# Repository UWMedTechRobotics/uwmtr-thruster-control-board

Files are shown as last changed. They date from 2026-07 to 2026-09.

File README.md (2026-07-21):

# Thruster Control Board - Revision 2

## Progress Notes
- Designed circuit board revision 1 using Altium Designer.
- Wrote firmware for testing circuitry on revision 1.
    - Wasn't able to use revision 1 tests due to faults in circuit design.
- Designed circuit board revision 2 using Altium Designer.

## Todo Things & Priority
### High
- [x] [@AdrianTarantino](https://github.com/AdrianTarantino) | Solder crystal 
oscillator to board.

- [ ] Test device functionality. View [this repository](https://github.com/UWMedTechRobotics/ESC_V1_Firmware_Tests/tree/main).
    - [ ] Validate I2C, GPIO, PWM and ADC.

- [ ] Implement firmware for interfacing with onboard electronics:
    - [ ] [IMU (BNO055)](https://www.bosch-sensortec.com/media/boschsensortec/downloads/datasheets/bst-bno055-ds000.pdf).
    Note that this may be controlled by Orange Pi instead.
    - [ ] Leak Sensor (ask Daniel).
    - [ ] Solonoids (ask Daniel).
    - [ ] Serial communication via USB Type-C.
        - Speak with Abdur about what information needs to be communicated and
        how that information needs to be formatted.
        - Use PuTTY to validate that it's working.
    - [ ] [@AdrianTarantino](https://github.com/AdrianTarantino) | 3-Phase BLDC 
    motors.
    - [x] [@AdrianTarantino](https://github.com/AdrianTarantino) | Muxes
    - [x] [@AdrianTarantino](https://github.com/AdrianTarantino) | [LED Driver](https://use.365.altium.com/librarycomponentsapi/api/v1/References/6CBF2630-7D49-4BC0-9B47-311861A12B9A). LED colour should follow this
    priority:
        - Red when failure.
        - Green when motors spinning.
        - Purple when communicating with external device.
        - Blue when idle.

### Medium
- [ ] Conan | Design mounting bracket for board.

- [ ] Source stantions for stacking power board, sonar board and thruster board.

### Low
- [ ] Develop diagnostic app:
    - Desktop app on PC
    - Sends commands via USB to the board.

- [ ] Add release to [GitHub repository](https://github.com/UWMedTechRobotics/uwmtr-thruster-control-board).
    - STEP file.
    - NC Drill, Gerber
    - BOM, Pick & Place

- [ ] Document everything that needs to be changed for revision 3:
    - [ ] Add 3-phase BLDC driver chip.
        - Ideally be able to set speed & direction via I2C or SPI.
    - [ ] Add BNO055 IMU to the board instead of the current IMU on the board.
    - [ ] Replace the debug connector with pin headers.
    - [ ] Add USB to UART chip to simplify USB communications.
    - [ ] Add an additional onboard LED purely for signalling that power is on.
     
# Revision 3 Notes
## Electrical
- Update motor control circuitry to use [the TI MCF8316A](https://www.ti.com/product/MCF8316A#pps).
    - Significantly simplifies electrical system and number of components on the board.
    - Available on JLCPCB parts library.
- Simplify USB communication with [TI TUSB3410](https://www.ti.com/product/TUSB3410).
    - Converts USB data to UART.
 - Add [BNO055](https://www.digikey.ca/short/m2jcv0r0) for IMU related data.
    - Available on JLCPCB parts library.
- Add dedicated LED purely for indicating power-on.
- Use Power MOSFETs

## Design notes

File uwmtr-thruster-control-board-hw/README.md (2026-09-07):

# Notes
- Voltage for buck converter must be set with `BUCK_SEL` parameters
    
    | `BUCK_SEL` Value | Voltage |
    | ---------------- | ------- |
    | 0b00 | 3.1 < 3.3 < 3.5 |
    | 0b01 | 4.6 < 5.0 < 5.4 |
    | 0b10 | 3.7 < 4.0 < 4.3 |
    | 0b11 | 5.2 < 5.7 < 6.2 | 

- Source THT 22R 1W resistor for buck converter with.

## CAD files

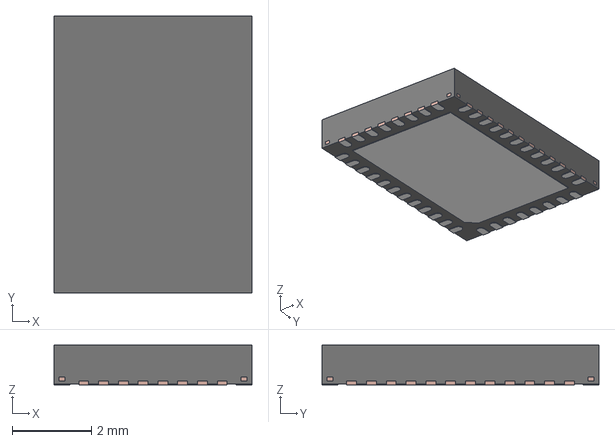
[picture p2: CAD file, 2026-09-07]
uwmtr-thruster-control-board-hw/uwmtr-thruster-control-board-hw-3d-models/TI_MCF8316A1VRGFR.stp
5.00 x 7.00 x 1.00 mm
FRAME

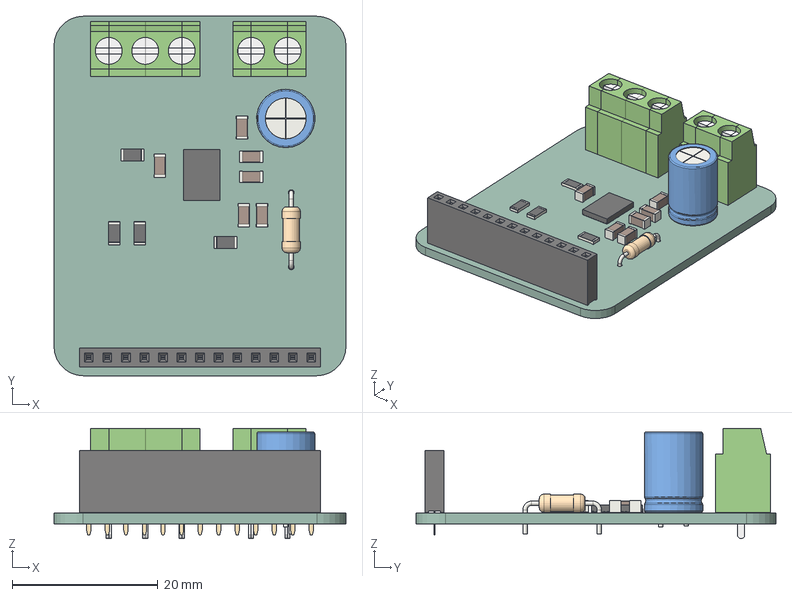
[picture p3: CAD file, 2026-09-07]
uwmtr-thruster-control-board-hw/uwmtr-thruster-control-board-hw-assembly/3d-models/uwmtr-thruster-control-board-hw.step
40.0 x 49.2 x 15.1 mm
R_1206_3216Metric x 4
C_1206_3216Metric x 6
MRT12P5_SX x 2
MRT12P5_CNT x 3
MRT12P5_DX x 2
C_Radial_D80mm_H115mm_P350mm
PinSocket_1x13_P2.54mm_Vertical
R_Axial_DIN0207_L63mm_D25mm_P1016mm_Horizontal
uwmA60_PCB

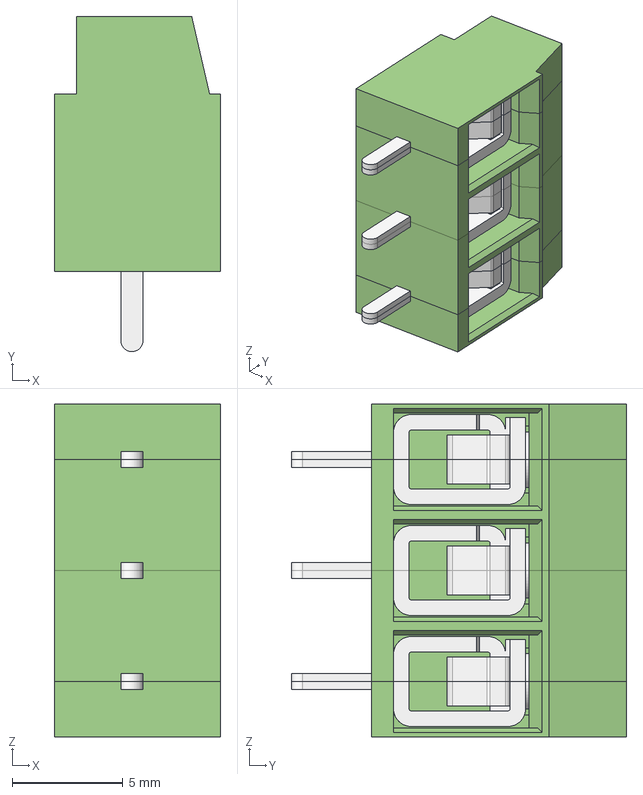
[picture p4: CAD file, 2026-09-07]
uwmtr-thruster-control-board-hw/uwmtr-thruster-control-board-hw-3d-models/Download_STP_691137710003_rev1.stp
7.50 x 15.1 x 15.0 mm
MRT12P5_SX
MRT12P5_CNT x 2
MRT12P5_DX

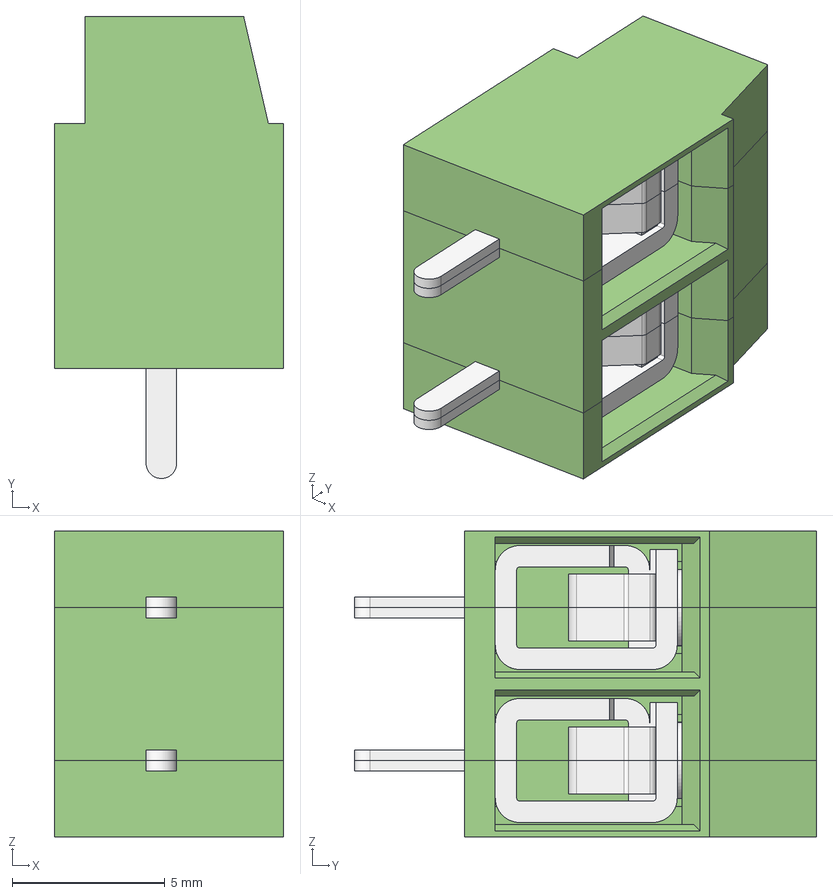
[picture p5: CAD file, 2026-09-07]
uwmtr-thruster-control-board-hw/uwmtr-thruster-control-board-hw-3d-models/691137710002.step
7.50 x 15.1 x 10.0 mm
MRT12P5_SX
MRT12P5_CNT
MRT12P5_DX

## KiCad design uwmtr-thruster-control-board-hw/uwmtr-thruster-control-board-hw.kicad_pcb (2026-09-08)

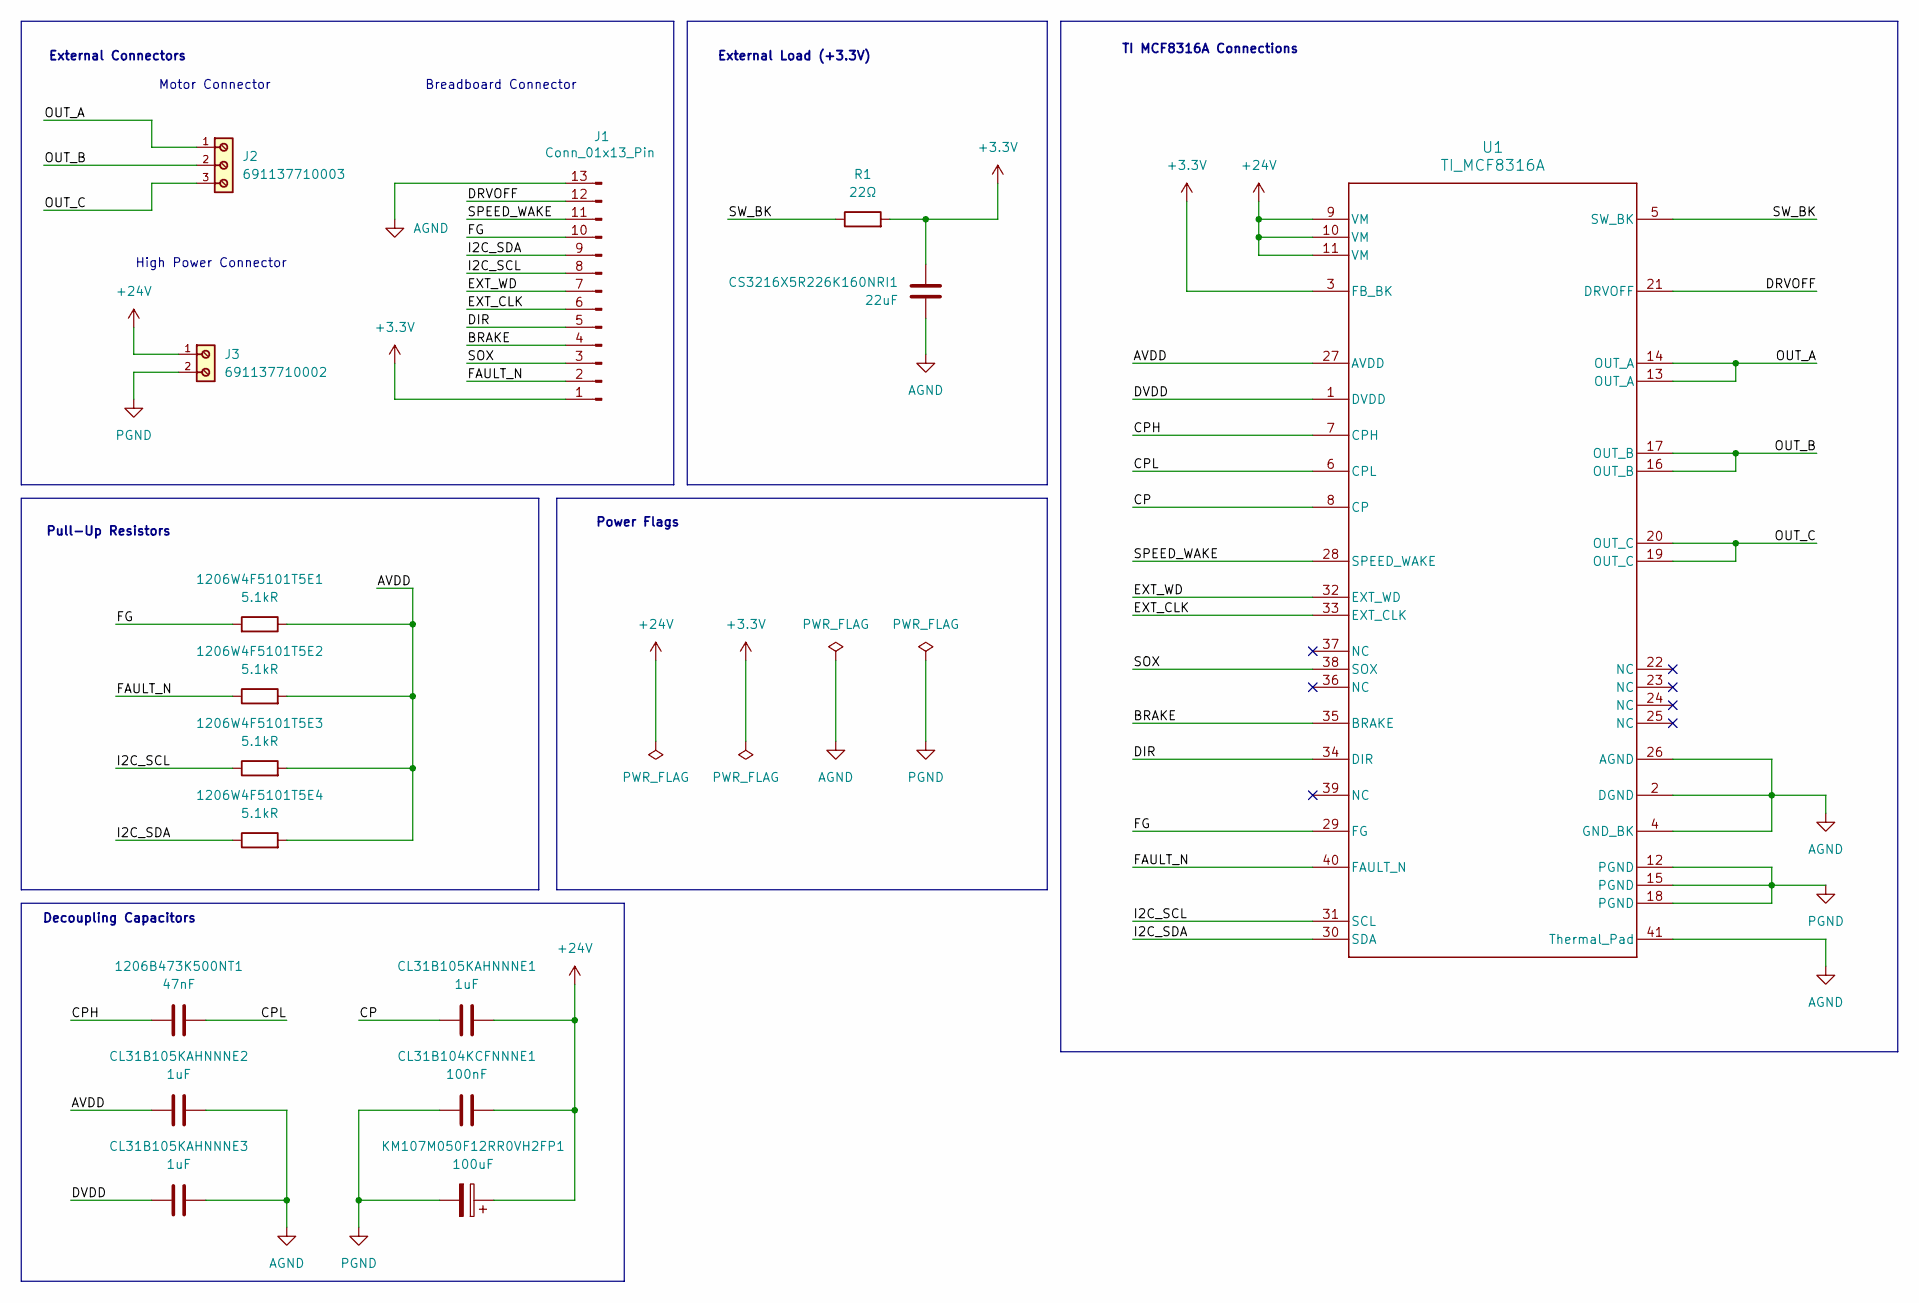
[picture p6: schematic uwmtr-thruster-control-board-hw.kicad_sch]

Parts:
1206B473K500NT1: 47nF; C_1206_3216Metric; JLCPCB Part # C1870
1206W4F5101T5E1, 1206W4F5101T5E2, 1206W4F5101T5E3, 1206W4F5101T5E4: 5.1kR; R_1206_3216Metric; JLCPCB Part # C26033
CL31B104KCFNNNE1: 100nF; C_1206_3216Metric; JLCPCB Part # C1945
CL31B105KAHNNNE1, CL31B105KAHNNNE2, CL31B105KAHNNNE3: 1uF; C_1206_3216Metric; JLCPCB Part # C28322
CS3216X5R226K160NRI1: 22uF; C_1206_3216Metric; JLCPCB Part # C513771
J1: Conn_01x13_Pin; PinSocket_1x13_P2.54mm_Vertical
J2: 691137710003
J3: 691137710002
KM107M050F12RR0VH2FP1: 100uF; C_Radial_D8.0mm_H11.5mm_P3.50mm; JLCPCB Part # C2749
R1: 22Ω; R_Axial_DIN0207_L6.3mm_D2.5mm_P10.16mm_Horizontal
U1: TI_MCF8316A; JLCPCB Part # C3681167

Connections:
+3.3V: CS3216X5R226K160NRI1.1, J1.1 (Pin_13), R1.2, U1.3 (FB_BK)
+24V: CL31B104KCFNNNE1.2, CL31B105KAHNNNE1.1, J3.1, KM107M050F12RR0VH2FP1.1, U1.9 (VM), U1.10 (VM), U1.11 (VM)
/AVDD: 1206W4F5101T5E1.1, 1206W4F5101T5E2.2, 1206W4F5101T5E3.2, 1206W4F5101T5E4.2, CL31B105KAHNNNE2.2, U1.27 (AVDD)
/BRAKE: J1.4 (Pin_10), U1.35 (BRAKE)
/CP: CL31B105KAHNNNE1.2, U1.8 (CP)
/CPH: 1206B473K500NT1.1, U1.7 (CPH)
/CPL: 1206B473K500NT1.2, U1.6 (CPL)
/DIR: J1.5 (Pin_9), U1.34 (DIR)
/DRVOFF: J1.12 (Pin_2), U1.21 (DRVOFF)
/DVDD: CL31B105KAHNNNE3.2, U1.1 (DVDD)
/EXT_CLK: J1.6 (Pin_8), U1.33 (EXT_CLK)
/EXT_WD: J1.7, U1.32 (EXT_WD)
/FAULT_N: 1206W4F5101T5E2.1, J1.2 (Pin_12), U1.40 (FAULT_N)
/FG: 1206W4F5101T5E1.2, J1.10 (Pin_4), U1.29 (FG)
/I2C_SCL: 1206W4F5101T5E3.1, J1.8 (Pin_6), U1.31 (SCL)
/I2C_SDA: 1206W4F5101T5E4.1, J1.9 (Pin_5), U1.30 (SDA)
/OUT_A: J2.1, U1.13 (OUT_A), U1.14 (OUT_A)
/OUT_B: J2.2, U1.16 (OUT_B), U1.17 (OUT_B)
/OUT_C: J2.3, U1.19 (OUT_C), U1.20 (OUT_C)
/SOX: J1.3 (Pin_11), U1.38 (SOX)
/SPEED_WAKE: J1.11 (Pin_3), U1.28 (SPEED_WAKE)
/SW_BK: R1.1, U1.5 (SW_BK)
AGND: CL31B105KAHNNNE2.1, CL31B105KAHNNNE3.1, CS3216X5R226K160NRI1.2, J1.13 (Pin_1), U1.2 (DGND), U1.4 (GND_BK), U1.26 (AGND), U1.41 (Thermal_Pad)
PGND: CL31B104KCFNNNE1.1, J3.2, KM107M050F12RR0VH2FP1.2, U1.12 (PGND), U1.15 (PGND), U1.18 (PGND)

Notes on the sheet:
High Power Connector
Decoupling Capacitors
External Connectors
Power Flags
Pull-Up Resistors
TI MCF8316A Connections
Motor Connector
Breadboard Connector
External Load (+3.3V)

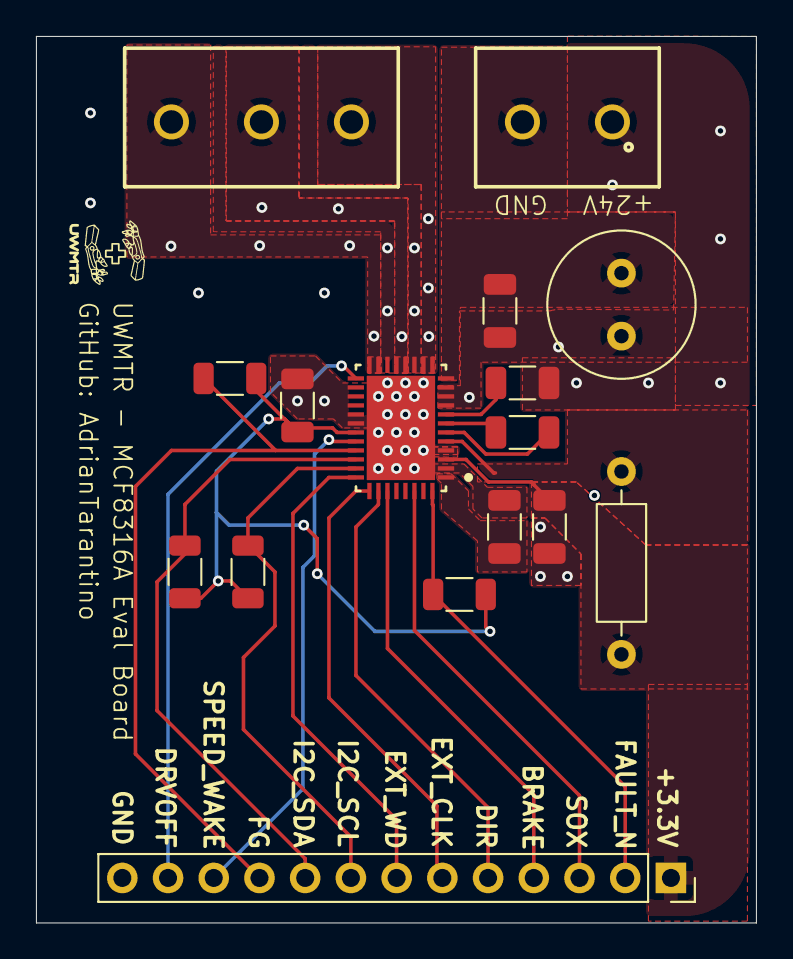
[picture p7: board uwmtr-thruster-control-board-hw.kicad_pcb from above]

Board: 4 copper layers, 40.0 x 49.2 mm, 16 parts (0 on the bottom side), 24 nets.

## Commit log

2026-07-20 Adding LED controller code to repo.
2026-07-20 Completing setup for new driver
2026-07-21 Updating build tools & Implementing mux driver.
2026-07-21 Updating project task board README file.
2026-08-25 Beginning schematic for breakout board.
    [TI_MCF8316A1VRGFR.stp, uwmtr-thruster-control-board-hw.kicad_pcb, uwmtr-thruster-control-board-hw.kicad_sch]
2026-08-25 Fixing git tree and commiting new schematic revision.
    [691137710002.step, Download_STP_691137710003_rev1.stp, uwmtr-thruster-control-board-hw.kicad_sch]
2026-08-25 Adding a bit of routing
    [uwmtr-thruster-control-board-hw.kicad_pcb, uwmtr-thruster-control-board-hw.kicad_sch]
2026-08-27 Completing component placement for layout and replacing the resistor
    [uwmtr-thruster-control-board-hw.kicad_pcb, uwmtr-thruster-control-board-hw.kicad_sch]
2026-09-04 Adding some routes
    [uwmtr-thruster-control-board-hw.kicad_pcb]
2026-09-06 Adding routing for OUT_A, OUT_B and OUT_C
    [uwmtr-thruster-control-board-hw.kicad_pcb, uwmtr-thruster-control-board-hw.kicad_sch]
2026-09-06 Completing layout
    [uwmtr-thruster-control-board-hw.kicad_pcb, uwmtr-thruster-control-board-hw.kicad_sch]
2026-09-07 Creating all manufacturing files
    [uwmtr-thruster-control-board-hw-B_Cu.gbr, uwmtr-thruster-control-board-hw-B_Mask.gbr, uwmtr-thruster-control-board-hw-B_Paste.gbr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]
2026-09-07 Adding the step file
    [uwmtr-thruster-control-board-hw.step]
2026-09-08 Adding more labels.
    [uwmtr-thruster-control-board-hw.kicad_pcb]
